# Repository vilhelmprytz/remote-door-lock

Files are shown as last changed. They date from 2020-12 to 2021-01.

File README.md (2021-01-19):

# vilhelmprytz/remote-door-lock

Remote door lock using WeMos D1 MINI ESP32 (Arduino framework), React and Flask (Python). This is a DIY IoT solution.

## Introduction

The project consists of three main components. You can find detailed information about each component and deployment instructions in their folders respectively. All three components are required for the project to work.

Firstly, the ESP32 itself. It is meant to be mounted to the lock of a door with a servo. The servo is meant to turn the lock and therefore allowing the unlocking of the door. You could modify the project to also interact with doors that have a button to unlock them (or some other electrical way of unlocking the door). The code for the ESP32 software can be found in the `esp32` folder.

Secondly, there is a backend API written in Flask (Python). The API is meant to run on a server as a cloud application. The ESP32 will poll the API to determine whether the door should be locked or unlocked. All responses from the API is JSON. While there is no authentication between the API and the ESP32, all requests that modify the state of the lock or the users who have access to it require authentication via [Google Sign-In](https://developers.google.com/identity/sign-in/web/sign-in). The code for the API software can be found in the `backend` folder.

Thirdly, the project consists of a frontend. The frontend is written in React (JavaScript) and is also meant to run on a server/static web hosting. The React application is the UI for the backend, it performs GET/POST/DELETE requests against the API. The code for the frontend software can be found in the `frontend` folder.

## Equipment

- Wemos D1 Mini32 ESP32 or similar (with WiFi!)
- Servo Motor FS5103R or similar, see [datasheet](https://www.rhydolabz.com/documents/24/FS5103R_specs.pdf)

## Circuit Diagram/Schematic

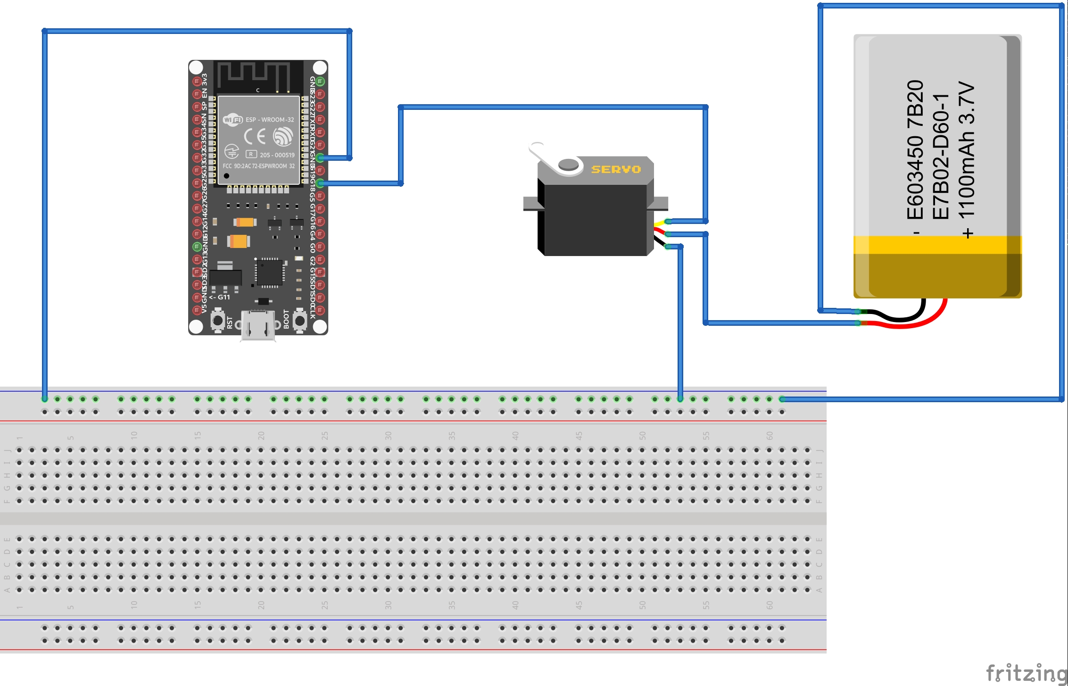
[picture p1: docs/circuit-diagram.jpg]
Circuit Diagram created with Fritzing


Note! The battery in the diagram is not accurate. The servo motor FS5103B recommends a voltage range of 4.8V to 6.0V while the battery in the diagram is 3.7V. With my testing, the servo works with lower voltages as well but it is not guaranteed. Adjust the battery to run with your servo.

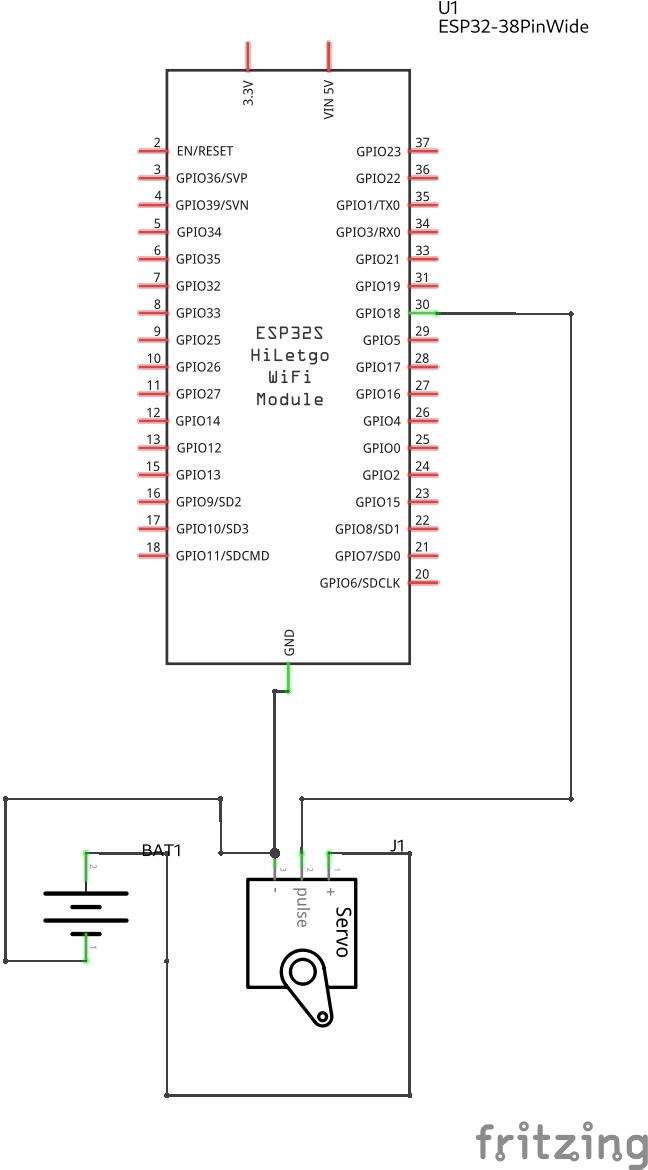
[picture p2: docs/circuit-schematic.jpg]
Circuit Schematic created with Fritzing


## Final Project and Video Demonstration

Example setup for the final project. There is also a [YouTube video](https://youtu.be/Ohy4-ShkAiI) demonstrating the project in action!

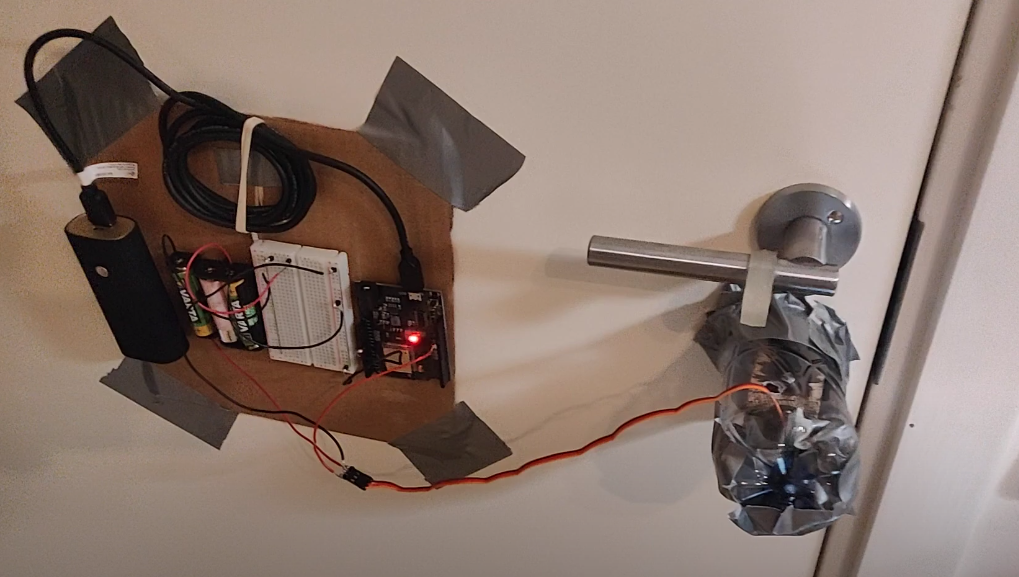
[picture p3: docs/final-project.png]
Final project


## Contributors ✨

Created and written by [Vilhelm Prytz](https://github.com/vilhelmprytz) - [vilhelm@prytznet.se](mailto:vilhelm@prytznet.se).

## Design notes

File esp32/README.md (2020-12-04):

# remote-door-lock/esp32

ESP32 software.

## Instructions

Use VS Code with the PlatformIO extension to build the project with the required dependencies. If you clone the project and open VS Code in this folder, VS Code will automatically recommend using PlatformIO since it's listed in `.vscode/extensions.json`. Use the schematic shown in the README in the project root. The PWM for the servo should be connected to the GPIO 18.

## Configuration

For the ESP32 software to work, you need to create a header file with some configuration variables. Create a file in the `include` folder with the name `BuildConfig.h`, i.e. `include/BuildConfig.h`.

Put the following contents in the file, modify the values of the constants. The variables are quite self-explanatory.

```c++
#define WIFI_SSID ""
#define WIFI_PASSWORD ""
#define API_ENDPOINT "http://10.0.1.226:5000/api/lock"
```

The `API_ENDPOINT` will be the Python backend API served at `/api`.

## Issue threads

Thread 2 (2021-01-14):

esp32: fix support for 360° servo

vilhelmprytz, 2021-01-14:
Currently slightly broken. Needs adjusting.

vilhelmprytz, 2021-01-15:
Fixed in 2e691b92c73c8c965e99839ac46b0ef2201e4a3f

Closed 2021-01-15.

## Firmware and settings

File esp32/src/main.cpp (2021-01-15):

#include <Arduino.h>
#include <WiFi.h>

// include classes
#include <Api.h>
#include <DoorServo.h>
#include <WiFiConn.h>

Api api;
DoorServo doorServo;
WiFiConn wifiConn;

const long refresh_interval = 1500;

void setup()
{
  // debugging, print to us
  Serial.begin(9600);

  wifiConn.setup();
}

void loop()
{
  // verify WiFi is alive
  wifiConn.alive();

  Serial.println("Refreshing data");

  // pass bool from API to doorServo to sync with server
  doorServo.sync(api.update());

  // wait until next refresh
  delay(refresh_interval);
}

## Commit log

2020-10-09 Initial servo-controller
2020-11-06 HTTP request via ESP32
2020-11-14 esp32: toggle now working
2020-11-15 esp32: update refresh interval
2020-11-29 frontend: set lock status locally before updateInfo() call
    * if the user spams the lock/unlock button it wont cause it to send same action multiple times
2020-12-01 Update documentation in README, add fritzing file
    [door-lock.fzz]
2020-12-02 esp32: update documentation
2020-12-02 Add circuit schematic
    [door-lock.fzz]
2020-12-03 docs: update circuit diagram, remove bendpoint
    [door-lock.fzz]
2020-12-04 docs: esp32: fix minor misspelling
2020-12-04 docs: clarify that voltage for servo is range between 4.8-6, not 4.8 OR 6
2020-12-04 esp32: refactor, split DoorServo and WiFiConn into own methods
    * all DoorServo interaction is now through own method, include/DoorServo.h
    * all WiFi interaction is now through own method, include/WiFiConn.h
2020-12-04 esp32: refactor API, DeserializeJson in Api.h and handle errors
    [main.cpp]
2020-12-04 travis ci: add pio ci test stage
2020-12-04 travis ci: remove cd esp32 since it's redundant
2020-12-09 esp32/docs: use servo FS5103R
2021-01-15 esp32: support 360 deg servo fully
2021-01-15 esp32: reformat code
2021-01-15 esp32: add a little bit of doc
2021-01-16 esp32: update servo turn time
2021-01-17 esp32: change door servo turn time
